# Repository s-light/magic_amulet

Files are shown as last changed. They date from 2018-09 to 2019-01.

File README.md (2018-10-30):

<!--lint disable list-item-indent-->
<!--lint disable list-item-bullet-indent-->
# Magic Amulet

a amulet with an power / guarding animal / creature

- it can magical glow
- useful as prop
- motive can be easily changed

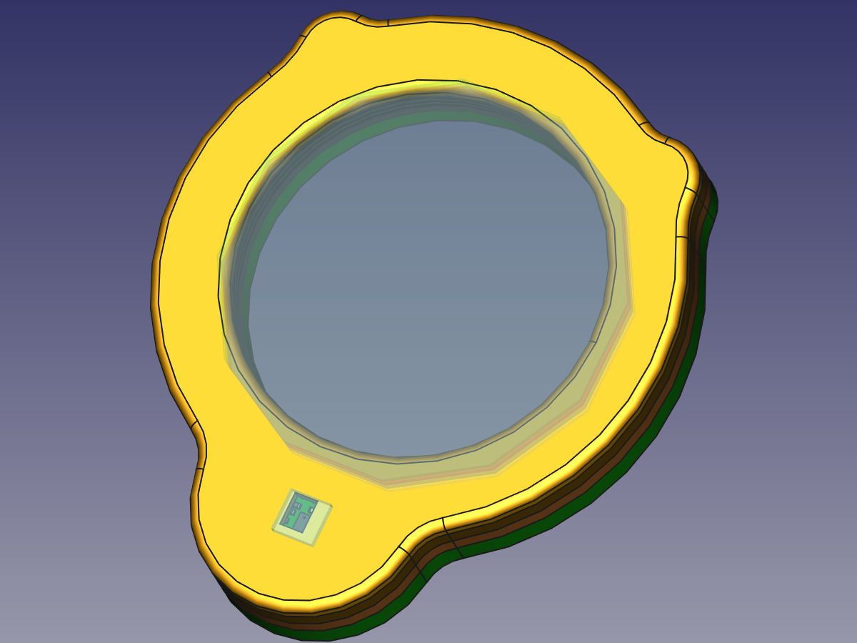
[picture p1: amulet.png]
overview amulet

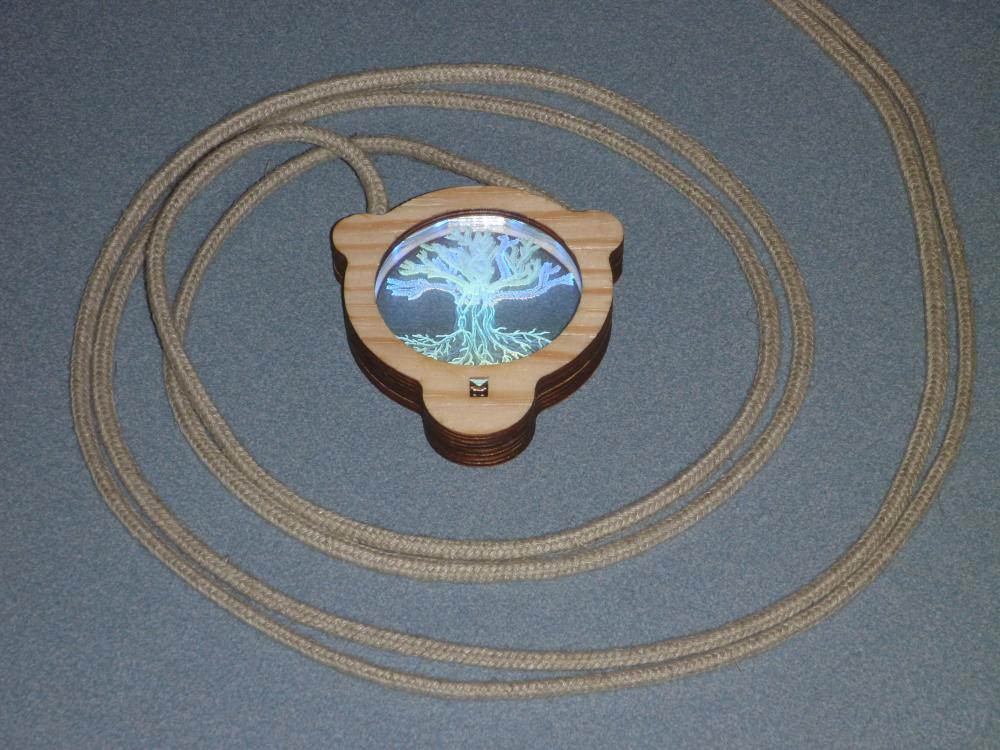
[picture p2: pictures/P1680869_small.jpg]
finished - detailed

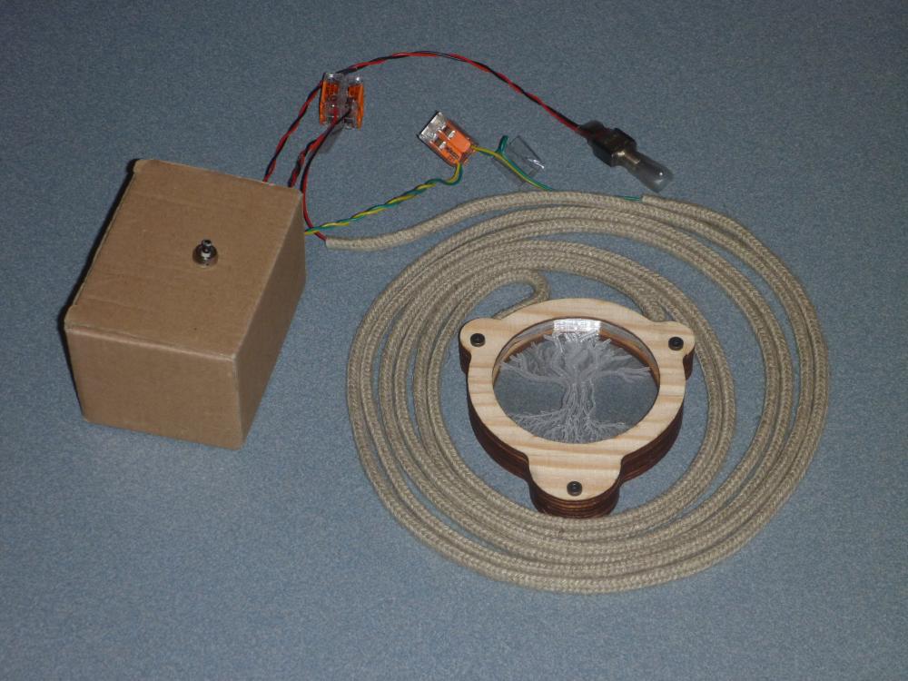
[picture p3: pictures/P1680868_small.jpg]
finished - with controller


## features
- material
    - wood
    - acrylic
- glowing / lighting effects
- creature / animal / symbol ideas
    - see [inspiration.md](inspiration.md)
    - saurian
    - lizard
    - owl
    - phoenix
    - dragon
    - moon
    - star
    - flower of life
    - tree of life

TODO: add art on front wood
some idea sketches

## housing
the housing is build from 4 Layers of 4mm pine plywood parts.  
the Acrylic inlay consists of 4 2mm parts.  
the Backside is hold by 3 M3-Screws.  
for this the nuts are inserted before the first three plywood parts
(front, in_front, in_back) are glued together.

## rope
- [Hanfseil HEMPBRAID von Kanirope ø5mm Meterware (lfm) 16-fach geflochten](https://www.kanirope.de/hanfseil-hempbraid-kanirope-5mm-meterware-lfm-16-fach-geflochten)

this rope has a core that can be exchanged with cables.
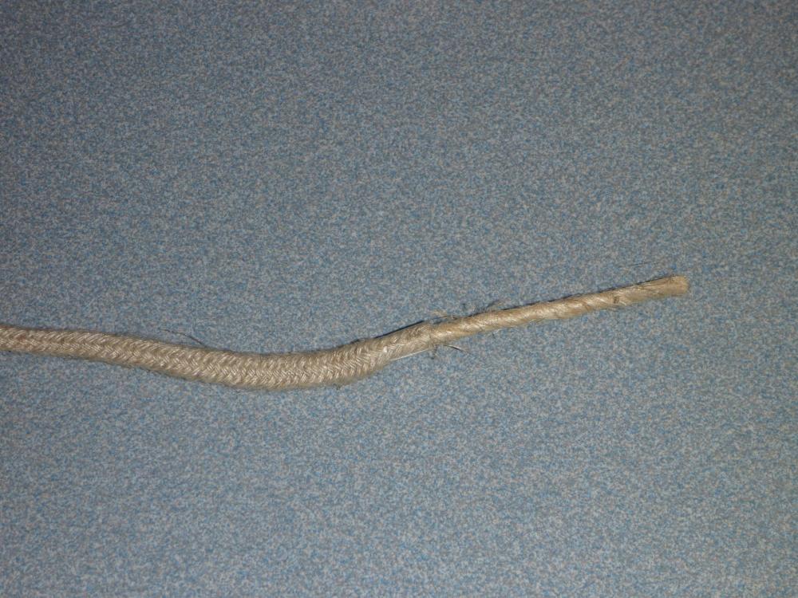
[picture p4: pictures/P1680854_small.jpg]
rope - core visible

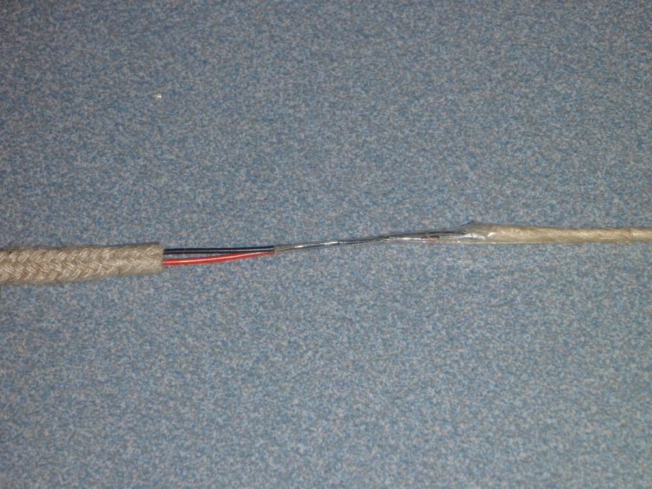
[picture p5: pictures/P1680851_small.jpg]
rope with cable

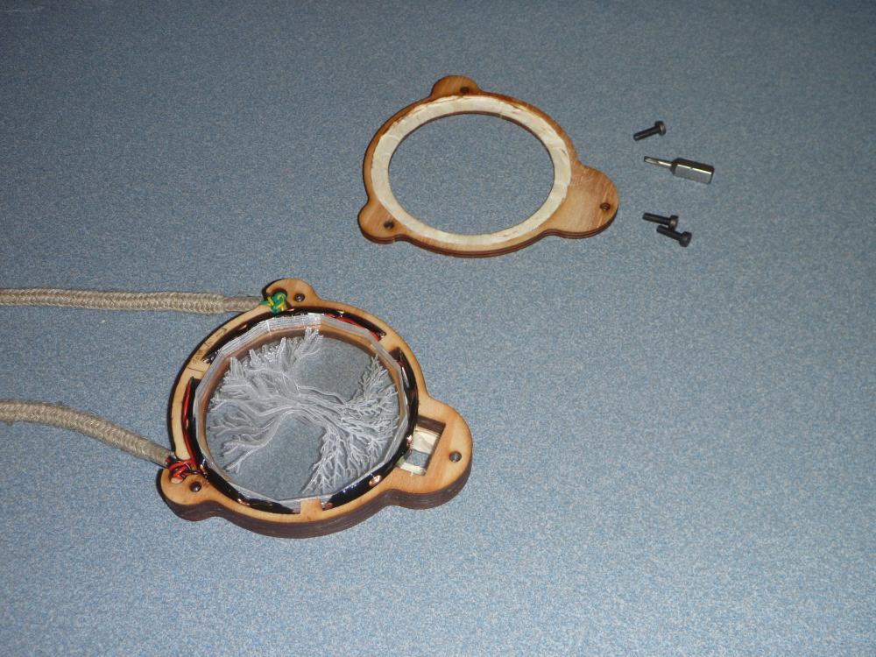
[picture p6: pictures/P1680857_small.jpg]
fitting the rope


## electronic

→ currently there is a APA102 60LEDs/m pixel-strip (3 segments with each 4LEDs)
fitted. (this was to get done in time :smile:)
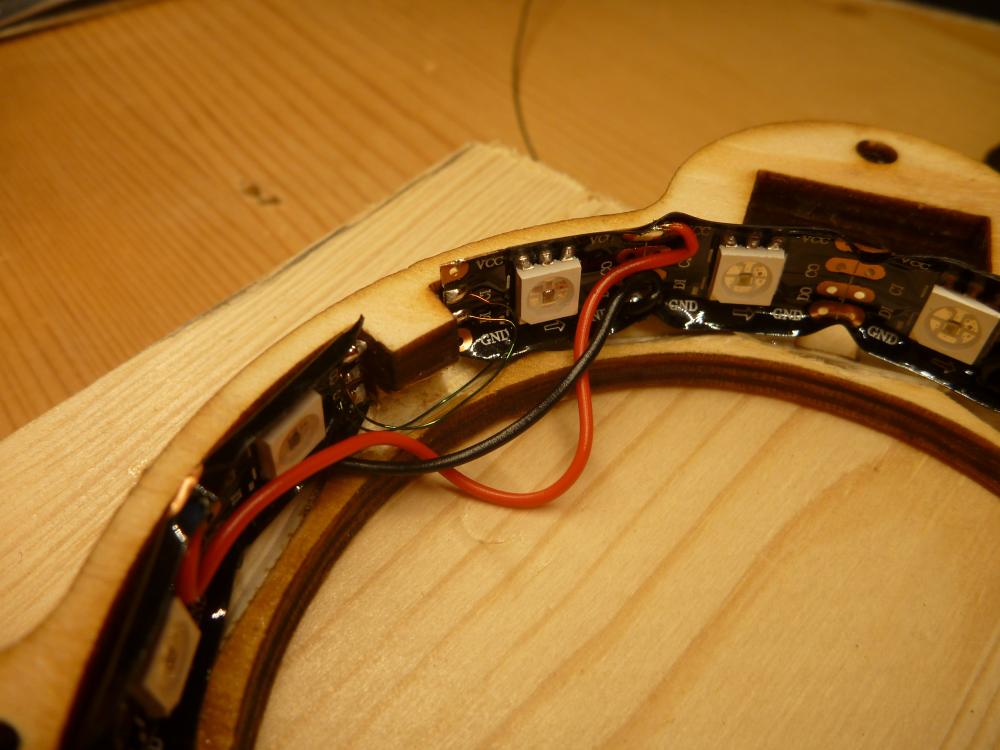
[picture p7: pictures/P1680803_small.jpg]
soldering APA102 strip in place


the electronic parts are hand-soldered / assembled.
for this there is a helper that can be manufactured out of >= 1mm cardboard
soldering helper
→ first iteration of this did not work. holes are to big.
but i managed to create a working test:
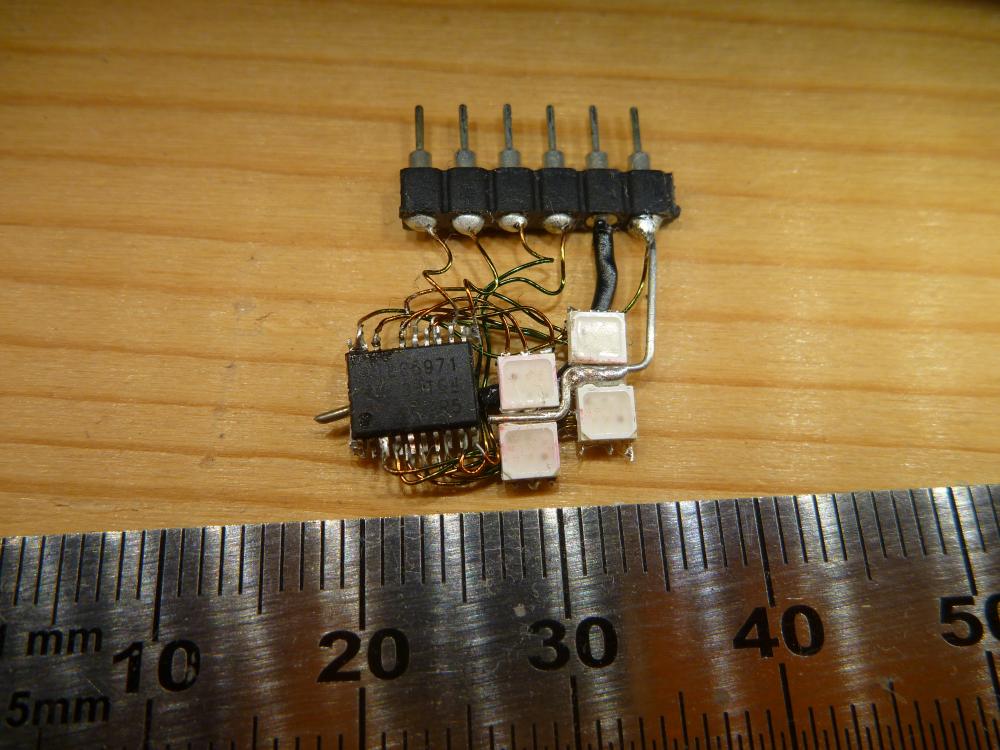
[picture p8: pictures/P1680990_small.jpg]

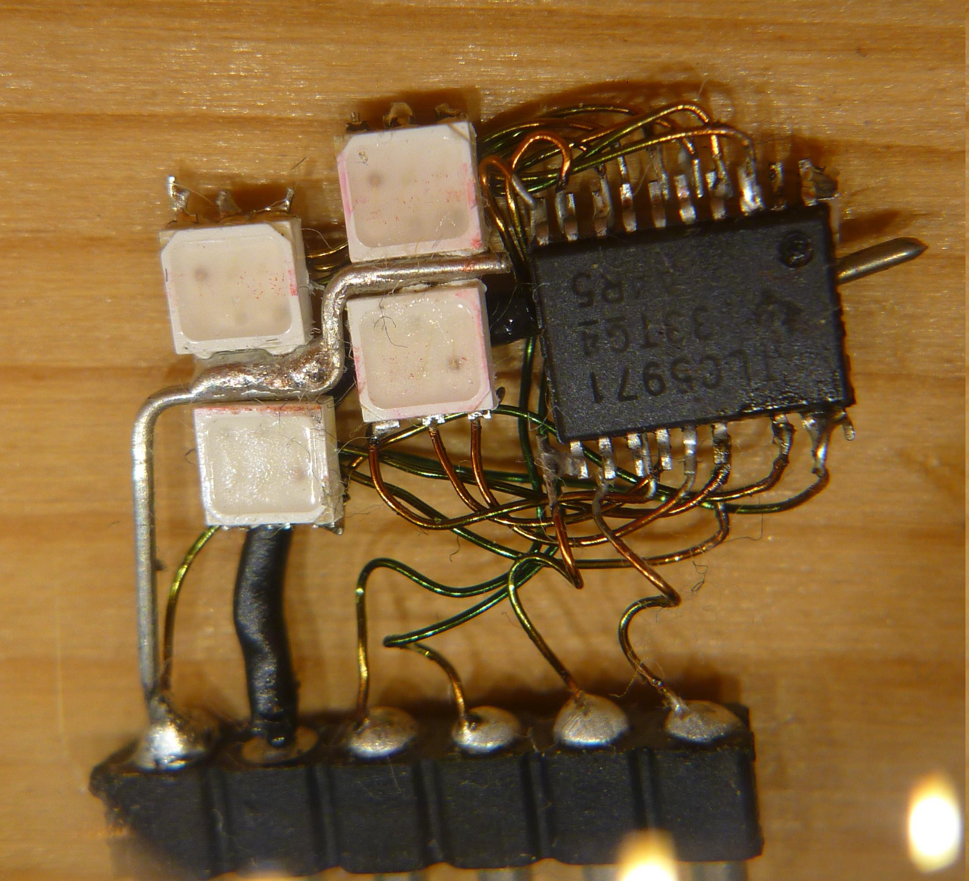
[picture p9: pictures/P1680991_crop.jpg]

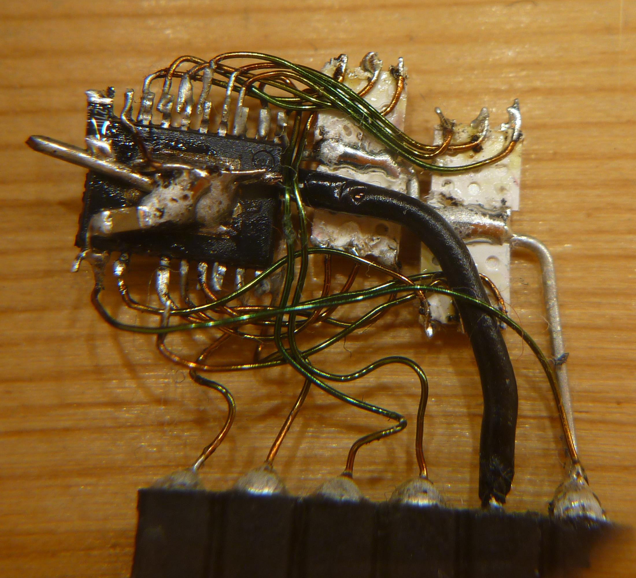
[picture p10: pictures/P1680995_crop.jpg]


#### Next Revision

pcb see [magic_amulet_pcbs / LEDBoard_4x4_HD](https://github.com/s-light/magic_amulet_pcbs)

and with a bunch of [sensors](sensors.md)

#### planed parts
- LEDs: Nichia 124 (switched to Rohm MSL0402RGB - they are smaller)
- driver: TLC5971 (switched to TLC5957 - just to test a new type :-) )

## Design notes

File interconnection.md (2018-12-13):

<!--lint disable list-item-indent-->
<!--lint disable list-item-bullet-indent-->
# Interconnection

this document describes ideas and concepts to interconnect the amulet with the controller / power box.

## data
for Data use LVDS or RS485 / RS422 to get the HighSpeed Signals from the controller to the LEDBoards.

[Recommend LVDS or RS422 / RS485 Driver and Receiver Pair for ~30MHz Signals](https://e2e.ti.com/support/interface/f/138/t/755140)

Hello TI-Community,

i have a 'art project' (costume) where i have some LED-Drivers (TLC5957) about 2meters away from my controller.
The Drivers have multiple Signals (GrayscaleClock, SignalClock, SignalData, Latch) that can go up to 30MHz.
So my Idea was to use RS485 / RS422 or LVDS to transmit this over the 2meter.

My Power Supply and IO Voltage is all 3.3V.
Can you Recommend any Drivers for this type of Application?
do i have advantages choosing one over the other technology?

for RS422 i have found this Pair:
- [AM26LV31E Low-Voltage High-Speed Quadruple Differential Line Driver With +/-15-kV IEC ESD Protection](http://www.ti.com/product/AM26LV31E)
- [AM26LV32E Low-Voltage High-Speed Quadruple Differential Line Receiver With +/-15-kV IEC ESD](http://www.ti.com/product/AM26LV32E)

for LVDS i have found this Pair:
- [SN65LVDS391 Quad LVDS Driver](http://www.ti.com/product/SN65LVDS391)
- [SN65LVDT348 Quad Receiver with -4 to 5V Common-mode Range](http://www.ti.com/product/SN65LVDT348)

is either a good choice?
or are there any other better suited parts?
additionally i have found this Info:
- [TI Designs: TIDA-060017 Transmitting SPI Signals Over LVDS Interface Reference Design](http://www.ti.com/lit/ug/tidued8/tidued8.pdf)
- [Blog - Get Connected: How to extend an SPI bus through a differential interface](https://e2e.ti.com/blogs_/b/analogwire/archive/2015/02/13/extending-spi-with-differential-signaling-technology)

i hope you can give me some tips :-)

sunny greetings
stefan

### cable

[SMARTflex Cat.6A U/UTP AWG32 LSOH Schwarz 5,0m](https://aixontec.com/SMARTflex-Cat6A-U-UTP-AWG32-LSOH-Schwarz-50m) 7.95€ + 5.9€ = 13.85€
super thin cable- with outer diameter of 2.8mm

### connector

[RJ45 connector - Bel SS-6488S-A-NF](https://www.mouser.de/ProductDetail/530-SS-6488S-A-NF) [datasheet](https://belfuse.com/resources/drawings/stewartconnector/dr-stw-ss-6488s-a-nf.pdf)

---

## power

use LiFePo4
```
4S
2.0V \* 4 = 8V
3.2V \* 4 = 12.8V
3.6V \* 4 = 14.4V
```

### cable

- [TKD - 01.05.01 HIGHFLEX LIFY](https://www.tkd-kabel.de/de/loesungen/produktbezogen/node-01.05-41/)
    price requested per mail
- [daims-kabelshop.de - 0,35mm² silicon highly flexible](https://shop.strato.de/epages/63697912.sf/sec9f439b4be0/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) 0.5€/m
- [daims-kabelshop.de - 0,50mm² silicon highly flexible](https://shop.strato.de/epages/63697912.sf/sec9f439b4be0/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) 0.6€/m
- [daims-kabelshop.de - 0,75mm² silicon highly flexible](https://shop.strato.de/epages/63697912.sf/sec9f439b4be0/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) 0.8€/m

### StepDown Converter

[2.95V to 17V, 10A Step-Down Power Module with Current Sharing in 10x10x4.3mm QFN Package](http://www.ti.com/product/lmz31710)
([mouser: 10,09€](https://www.mouser.de/Search/Refine.aspx?Keyword=LMZ31710))

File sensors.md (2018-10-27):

<!--lint disable list-item-indent-->
<!--lint disable list-item-bullet-indent-->
# Sensors

info's for the different Sensor Ideas that can be useful for interacting with the amulet

## Light & Gesture

[APDS-9960](https://www.broadcom.com/products/optical-sensors/integrated-ambient-light-and-proximity-sensors/apds-9960)
Digital RGB, Ambient Light, Proximity and Gesture Sensor

- [CircuitPython library available](https://circuitpython.readthedocs.io/projects/apds9960/en/latest/api.html).

## Distance

use [VL53L1X](https://www.st.com/en/imaging-and-photonics-solutions/vl53l1x.html)  
4-400cm ToF 940nm Laser sensor

#### cover glass
acryl glass - visible light
acryl glass - IR light

use the blue one in combination with real black.
or transparent with black.  

create cover glass window in 'sandwich' variant -  
like explained in this [video](https://www.youtube.com/watch?v=BHM2CZVXZGc&feature=youtu.be&t=166)

#### TODO
- write CircuitPython driver
    - [check this topic for some starting points](https://forum.micropython.org/viewtopic.php?t=4827)

## Ambient-Light Level

use [TSL2591](https://ams.com/tsl25911#tab/documents)  
already has
[arduino](https://learn.adafruit.com/adafruit-tsl2591/wiring-and-test#raw-data-access-api-4-25) and
[CircuitPython](https://learn.adafruit.com/adafruit-tsl2591/python-circuitpython#full-example-code-6-15) libraries

## Touch

use [FDC1004](http://www.ti.com/product/FDC1004)?  
it has a shield so eventually it could work while hanging at the body?  

#### TODO
- test if this works
- write CircuitPython driver

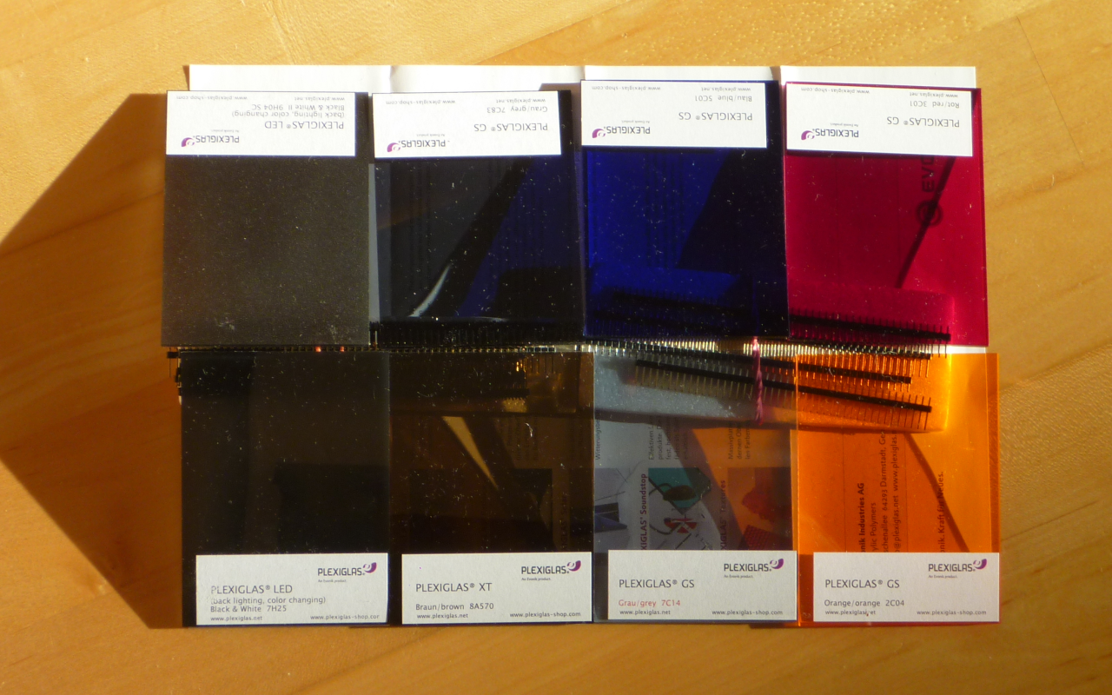
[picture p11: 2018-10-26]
pictures/acrylglass_IR_visibillity__only_VISIBLE.png

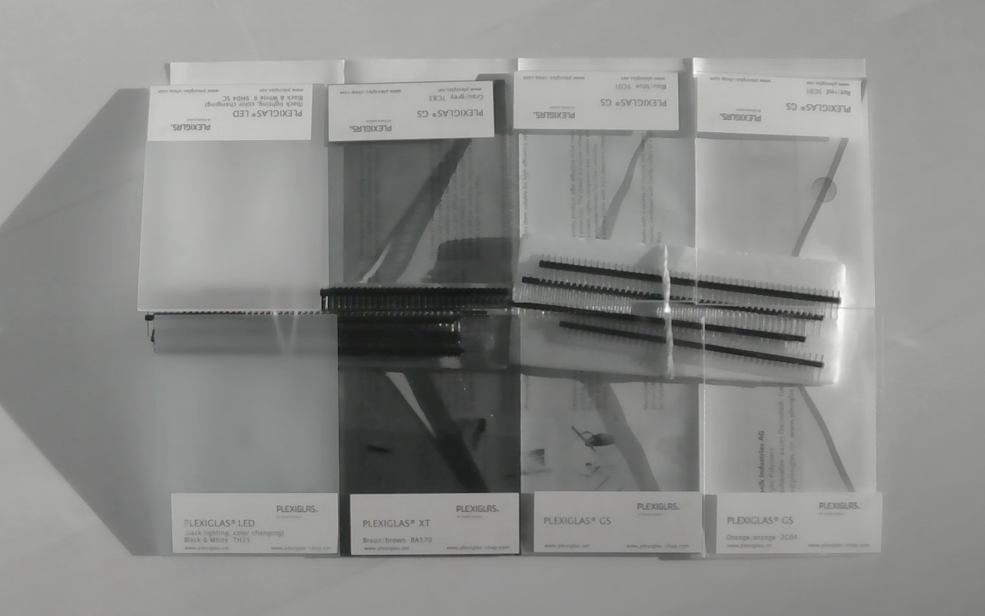
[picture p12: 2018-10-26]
pictures/acrylglass_IR_visibillity__only_IR.png

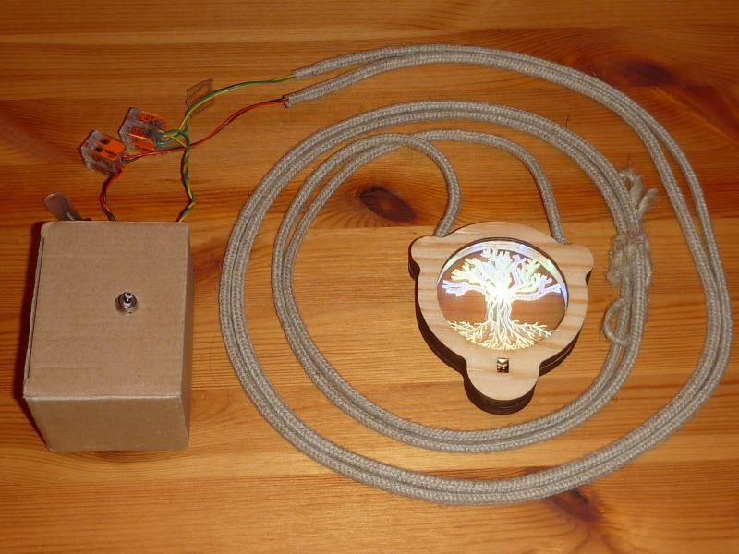
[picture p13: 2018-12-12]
pictures/P1700281_small.jpg

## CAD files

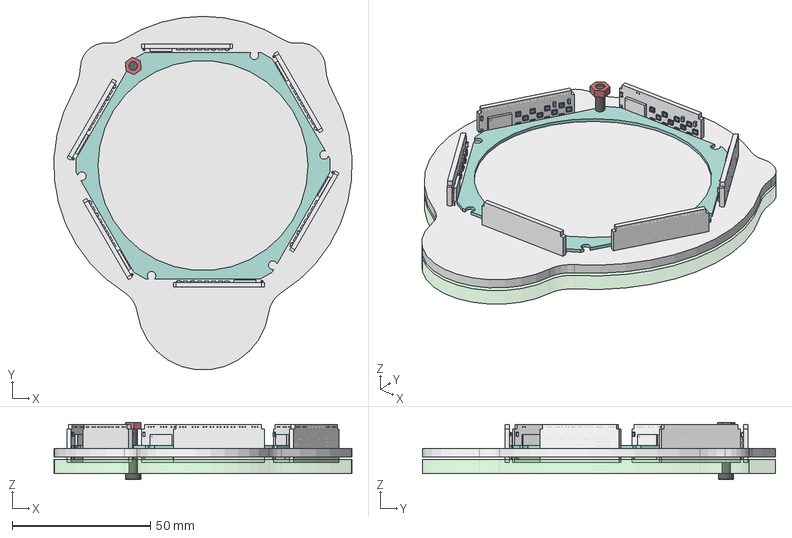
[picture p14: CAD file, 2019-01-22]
amulet.fcstd
107.8 x 127.9 x 20.8 mm
back_Body
back_layer_0_in_Body
back_layer_0_out_Body
LEDBoard_4x4_HD_sp
Nut_Body023
Screw_Body024

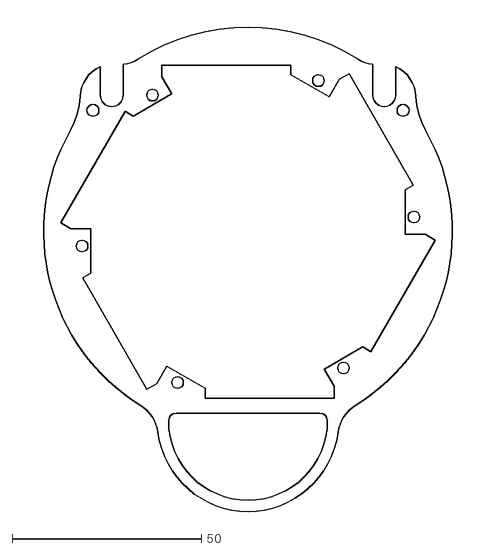
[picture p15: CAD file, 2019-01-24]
export/alu_layers/alu_layer_3.dxf
122.6 x 130.8

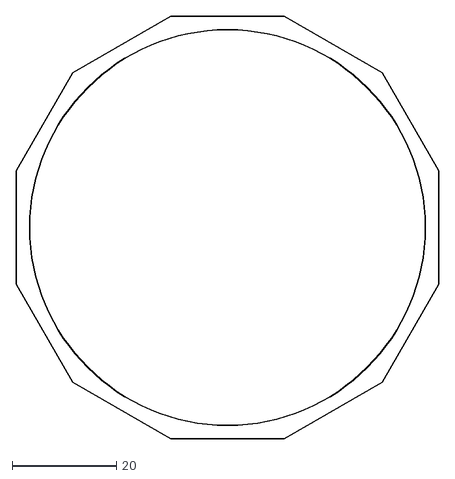
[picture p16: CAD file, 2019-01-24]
export/back_layers/back_layer_1.dxf
81.1 x 81.1

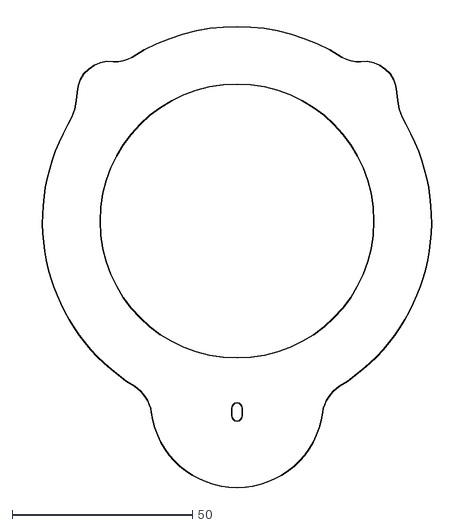
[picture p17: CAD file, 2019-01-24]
export/front_layers/front_layer_0_wEngraving.dxf
122.6 x 130.8

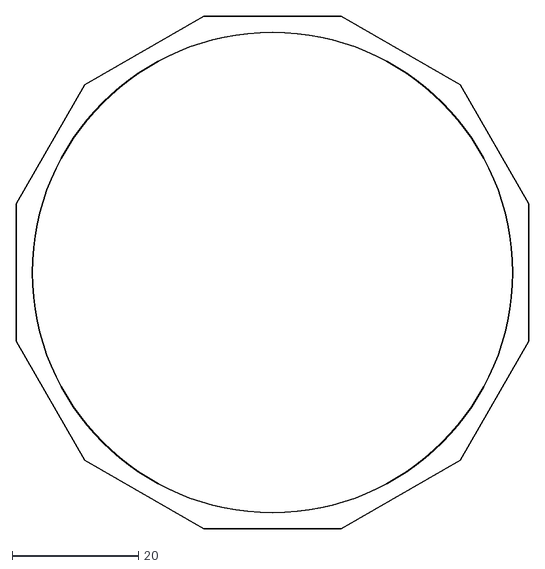
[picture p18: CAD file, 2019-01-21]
export/paper_separator.dxf
81.1 x 81.1

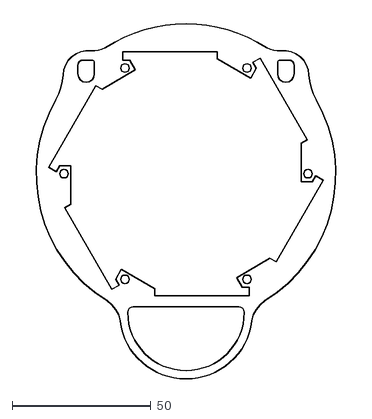
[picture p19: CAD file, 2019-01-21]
export/alu_layere_0.dxf
122.6 x 130.8

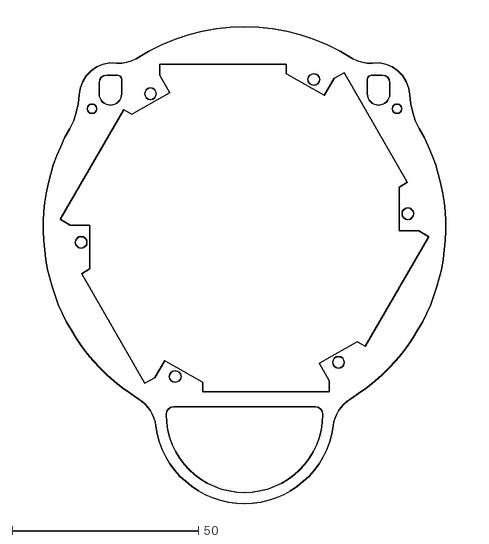
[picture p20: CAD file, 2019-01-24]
export/alu_layers/alu_layer_2.dxf
122.6 x 130.8

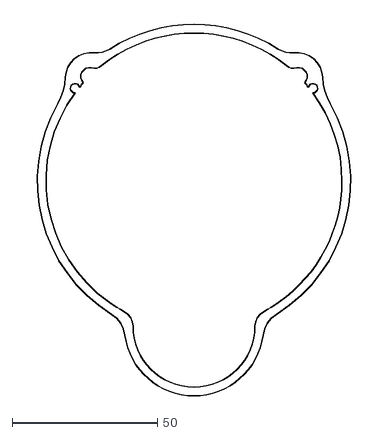
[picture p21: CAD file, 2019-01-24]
export/back_layers/back_layer_0_out.dxf
122.6 x 130.8

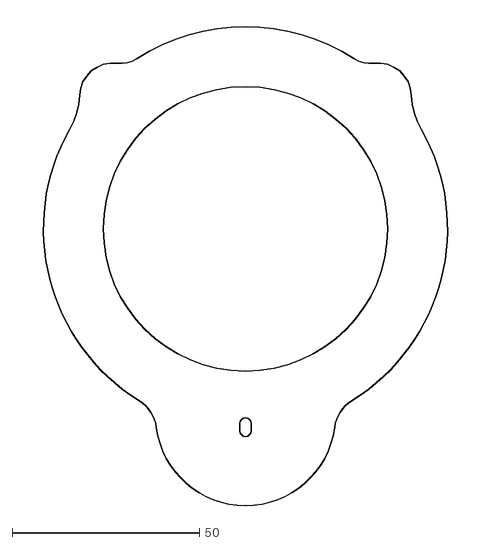
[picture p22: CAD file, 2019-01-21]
export/front_layers/front_layer_0.dxf
122.6 x 130.8

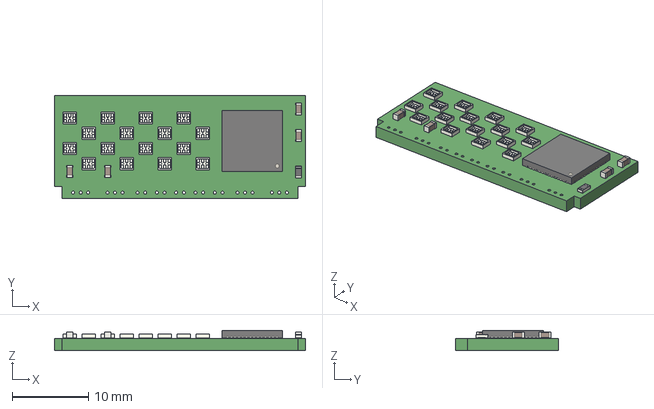
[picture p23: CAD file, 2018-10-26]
LEDBoard_4x4_HD.step
33.0 x 13.6 x 2.65 mm

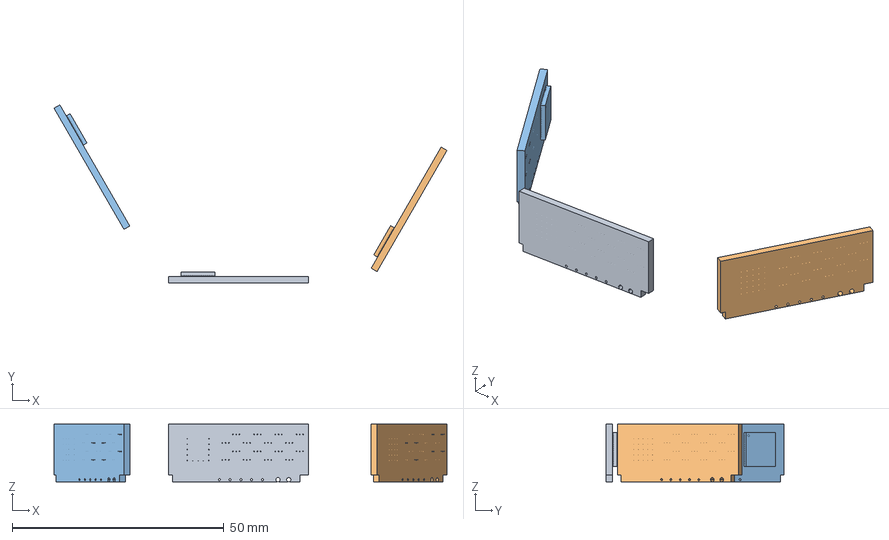
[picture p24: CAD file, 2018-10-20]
amulet_pcb_sizetest.fcstd
92.7 x 42.1 x 13.6 mm
LEDBoard_4x4_HD

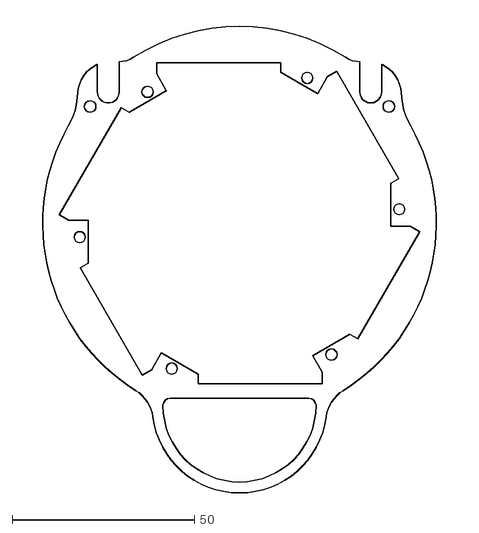
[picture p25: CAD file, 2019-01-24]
export/alu_layers/alu_layer_4.dxf
122.6 x 130.8

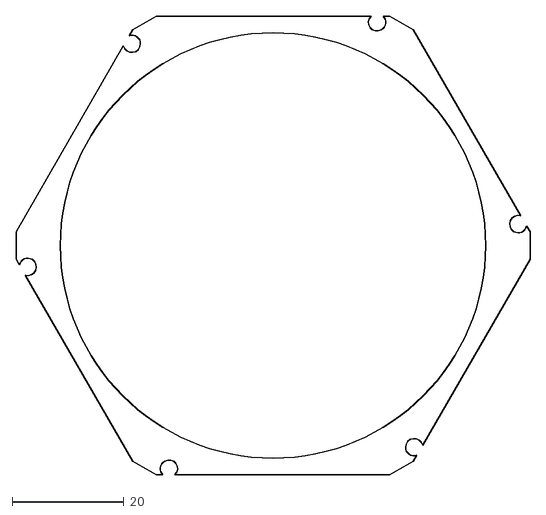
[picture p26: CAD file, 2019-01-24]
export/back_layers/back_layer_0_in.dxf
91.9 x 82.0

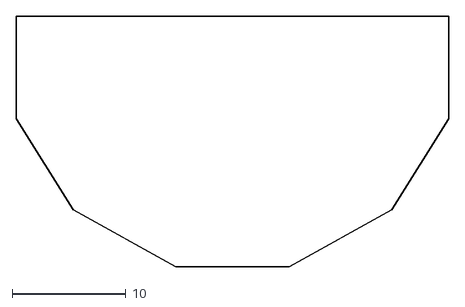
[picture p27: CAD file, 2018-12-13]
export/controller_pcb_outline.dxf
38.0 x 22.0

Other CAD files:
pattern_ideas/pattern_test_knot4_path.FCStd
export/front_layers/front_layer_3.dxf
export/alu_layers/alu_layer_1.dxf
export/back_layers/back_layer_2.dxf
export/alu_layers/alu_layer_0.dxf
export/back.dxf
export/front.dxf
export/front_layers/front_layer_1_in.dxf
export/front_layers/front_layer_1_out.dxf
export/front_layers/front_layer_2.dxf
export/in_back.dxf
export/in_front.dxf
export/plexiglas.dxf
export/plexiglas_L1.dxf
export/plexiglas_L2.dxf
export/plexiglas_L2_fill.dxf
export/plexiglas_L3.dxf
export/plexiglas_L4.dxf
export/plexiglas_L4_fill.dxf
led_soldering_helper.dxf

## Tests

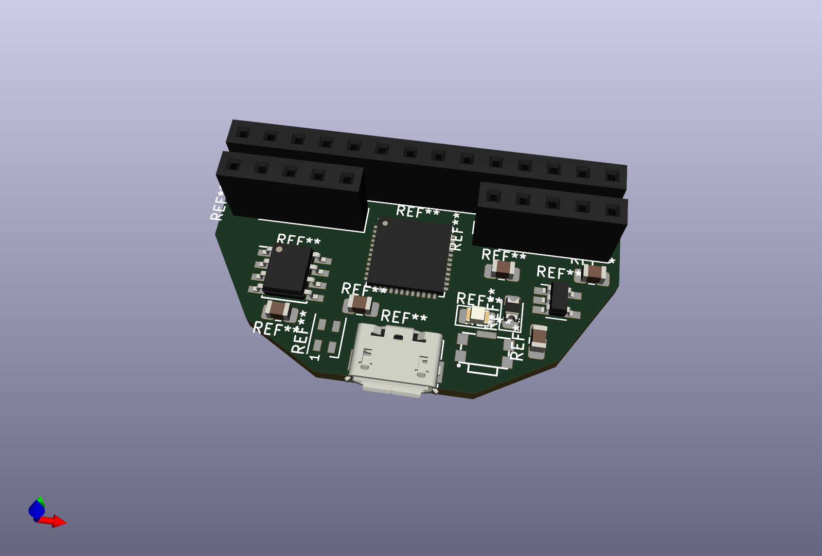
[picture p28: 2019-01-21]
controller_pcb_test.png

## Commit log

2018-09-11 added first amulet version
    [amulet.fcstd]
2018-09-11 updated to V2
    [amulet.fcstd]
2018-09-11 updated to V3
    [amulet.fcstd]
2018-09-11 added exported and modified files
    [back.dxf, front.dxf, in_back.dxf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]
2018-09-11 added more info in readme
    [led_soldering_helper.dxf]
2018-09-28 prepared amulet for pcb
    [amulet.fcstd]
2018-10-05 added pictures of test pcb
2018-10-20 intergrated new pcbs
    [LEDBoard_4x4_HD.step, amulet.fcstd, amulet_pcb_sizetest.fcstd]
2018-10-20 exported plexiglas & modifications
    [plexiglas.dxf, plexiglas_L1.dxf, plexiglas_L2_fill.dxf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]
2018-10-21 fixed exported L4_filled
    [plexiglas_L4_fill.dxf]
2018-10-26 updated CAD construction
    [LEDBoard_4x4_HD.step, amulet.fcstd]
2018-10-26 updated LEDBoard in amulet construction
    [amulet.fcstd]
2018-10-27 refining construction
    [amulet.fcstd]
2018-10-27 adding another sensor option
2018-10-30 updated design with new alu plate concept
    [amulet.fcstd]
2018-12-12 cad construction
    [amulet.fcstd]
2018-12-12 rotated LEDBoard
    [amulet.fcstd]
2018-12-12 LEDBoards rotated and front fitted
    [amulet.fcstd]
2018-12-13 prepared sensor area
    [amulet.fcstd]
2018-12-13 switched connector type
2018-12-13 tested for included controller
    [amulet.fcstd, controller_pcb_outline.dxf, controller_pcb_test.kicad_pcb]
2019-01-21 add test for controller pcb
2019-01-21 CAD: added layered front
    [amulet.fcstd]
2019-01-21 CAD - export
    [alu_layere_0.dxf, front_layer_0.dxf, front_layer_1_in.dxf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]
2019-01-21 CAD prepared back_layered
    [amulet.fcstd]
2019-01-22 CAD back_layered design
    [amulet.fcstd]
2019-01-24 CAD + export
    [alu_layer_0.dxf, alu_layer_1.dxf, alu_layer_2.dxf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]
